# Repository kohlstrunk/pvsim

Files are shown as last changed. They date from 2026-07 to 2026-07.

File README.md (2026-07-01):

PVSIM

PV-Modul-Simulator
- getestet an Hoymiles HMS-800W-2T
- erlaubt DC-seitige Einstellung der Einspeiseleistung

Enthält:
- WinAVR-Projekt
- Eagle-Schaltplan und Layout
- Fertigungsdaten

Entwicklungsstand
- Erprobung 2-Kanalig an beiden separaten MPPT-Kanälen
- Erprobung 1-kanalig mit parallel geschalteten MPPT-Kanälen
- Erprobung mit Si-H-Brücke 50V 50A bei 62kHz Schaltfrequenz

Perspektive:
- Umstellung auf 250kHz GaN-Halbbrücke 20A mit parallel geschalteten MPPT-Kanälen

Links:
- https://www.mikrocontroller.net/topic/585740
- https://epc-co.com/epc/products/gan-fets-and-ics/epc23109

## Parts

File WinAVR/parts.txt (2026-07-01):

https://www.reichelt.de/de/de/shop/produkt/dc_dc-wandler_75_v_sip-396833
https://www.reichelt.de/de/de/shop/produkt/dc_dc-wandler_72_v_sip-396834

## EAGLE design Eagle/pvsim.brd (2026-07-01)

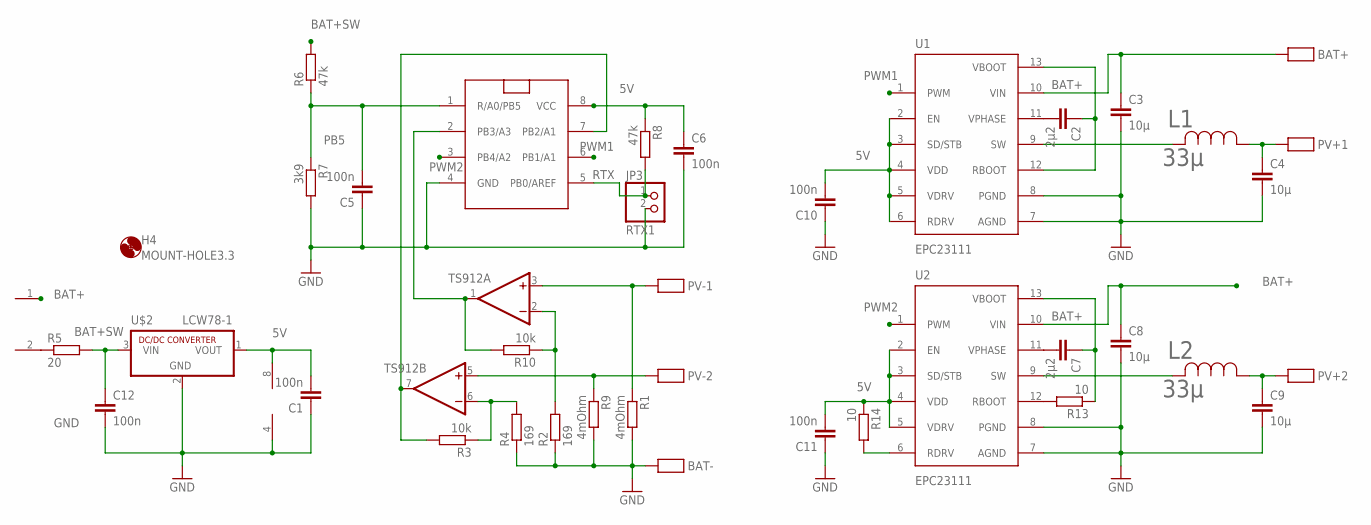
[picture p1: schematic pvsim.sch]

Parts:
BAT+: SMD_10X5
BAT-: SMD_10X5
C1, C5, C6, C10, C11, C12: 100n; C0805
C2: 2µ2; C0805K
C3, C4, C8, C9: 10µ; C1210K
C7: 2µ2; C1206K
FK1: Start; DG250-3.5-2
H4: MOUNT-HOLE3.3; 3,3
JP3: RTX1; 1X02
L1, L2: 33µ; IND_PA4349.333ANLT_PUL-M
PV+1, PV+2: SMD_10X5
PV-1, PV-2: SMD_10X5
R1, R9: 4mOhm; R2512
R2, R4: 169; R0805
R3, R10: 10k; R0805
R5: 20; 0207/10
R6, R8: 47k; R0805
R7: 3k9; R0805
R13, R14: 10; R0805
TS912: 2AMP_P8+4D; SO08
U1, U2: EPC23111; EPC23111_QFN13_EPC_LP
U$2: LCW78-1; SIP3
U$4: FUNKY; FUNKYTINY

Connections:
5V: C1.2, C6.1, C10.2, C11.2, R8.1, R14.1, TS912.8 (V+), U1.2 (EN), U1.3 (SD/STB), U1.4 (VDD), U1.5 (VDRV), U1.6 (RDRV), U2.2 (EN), U2.3 (SD/STB), U2.4 (VDD), U2.5 (VDRV), U$2.1 (VOUT), U$4.8 (VCC)
BAT+: BAT+.P$1, C3.1, C8.1, FK1.1, U1.10 (VIN), U2.10 (VIN)
BAT+SW: C12.1, R5.2, R6.2, U$2.3 (VIN)
BAT-: R9.2
GND: BAT-.P$1, C1.1, C3.2, C4.2, C5.1, C6.2, C8.2, C9.2, C10.1, C11.1, C12.2, JP3.2, R1.2, R2.1, R4.1, R7.2, TS912.4 (V-), U1.7 (AGND), U1.8 (PGND), U2.7 (AGND), U2.8 (PGND), U$2.2 (GND), U$4.4 (GND)
IPV1: PV-1.P$1, R1.1, TS912.3 (+IN)
IPV2: PV-2.P$1, R9.1, TS912.5 (+IN)
unnamed: R10.2, TS912.1 (OUT), U$4.2 (PB3/A3)
unnamed: R2.2, R10.1, TS912.2 (-IN)
unnamed: R3.2, TS912.7 (OUT), U$4.7 (PB2/A1)
unnamed: R3.1, R4.2, TS912.6 (-IN)
unnamed: FK1.2, R5.1
unnamed: C2.1, U1.12 (RBOOT), U1.13 (VBOOT)
unnamed: C2.2, U1.11 (VPHASE)
unnamed: C4.1, L1.1, PV+1.P$1
unnamed: L1.2, U1.9 (SW)
unnamed: C7.1, R13.1, U2.13 (VBOOT)
unnamed: C7.2, U2.11 (VPHASE)
unnamed: L2.2, U2.9 (SW)
unnamed: C9.1, L2.1, PV+2.P$1
unnamed: R13.2, U2.12 (RBOOT)
PB5: C5.2, R6.1, R7.1, U$4.1 (R/A0/PB5)
PWM1: U1.1 (PWM), U$4.6 (PB1/A1)
PWM2: U2.1 (PWM), U$4.3 (PB4/A2)
RTX: JP3.1, R8.2, U$4.5 (PB0/AREF)

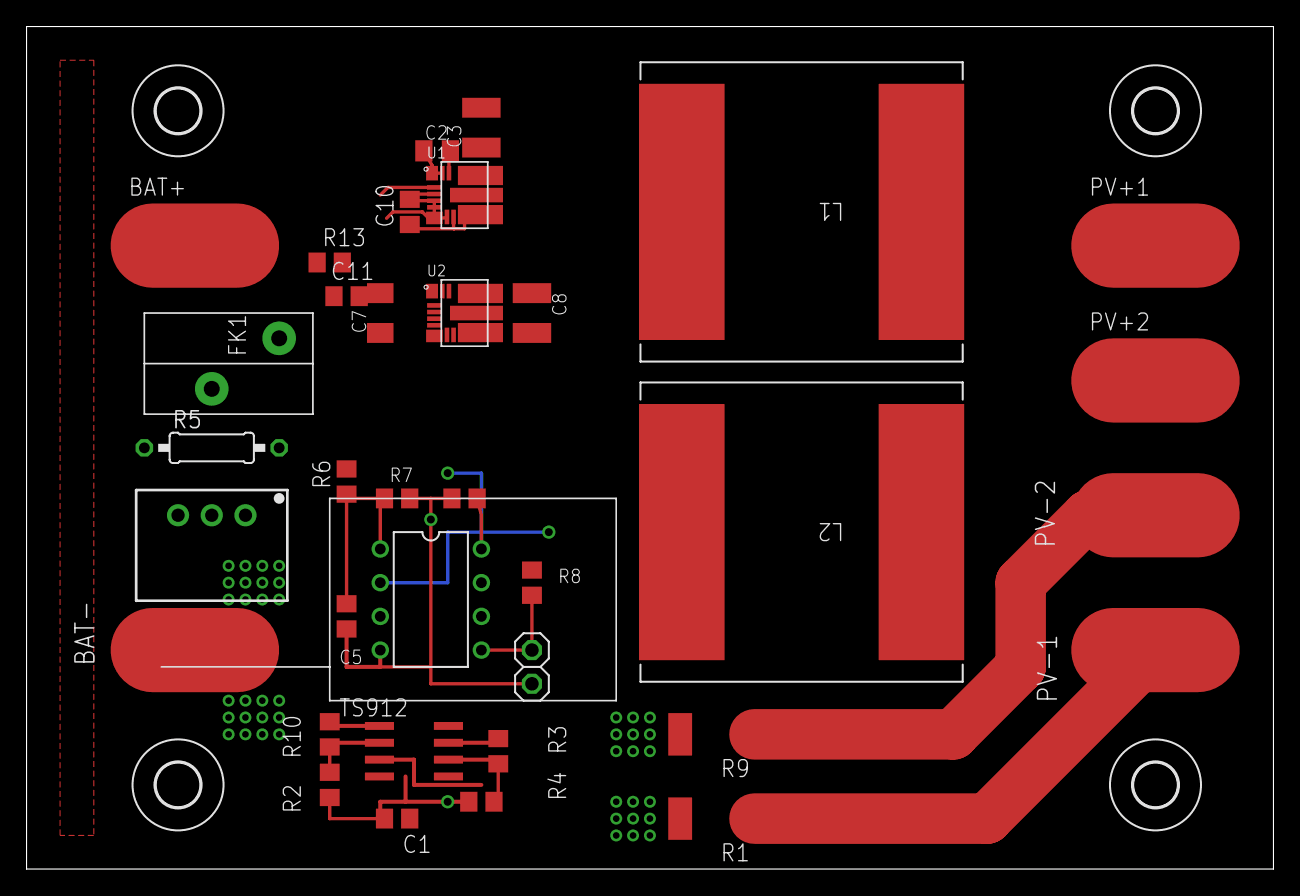
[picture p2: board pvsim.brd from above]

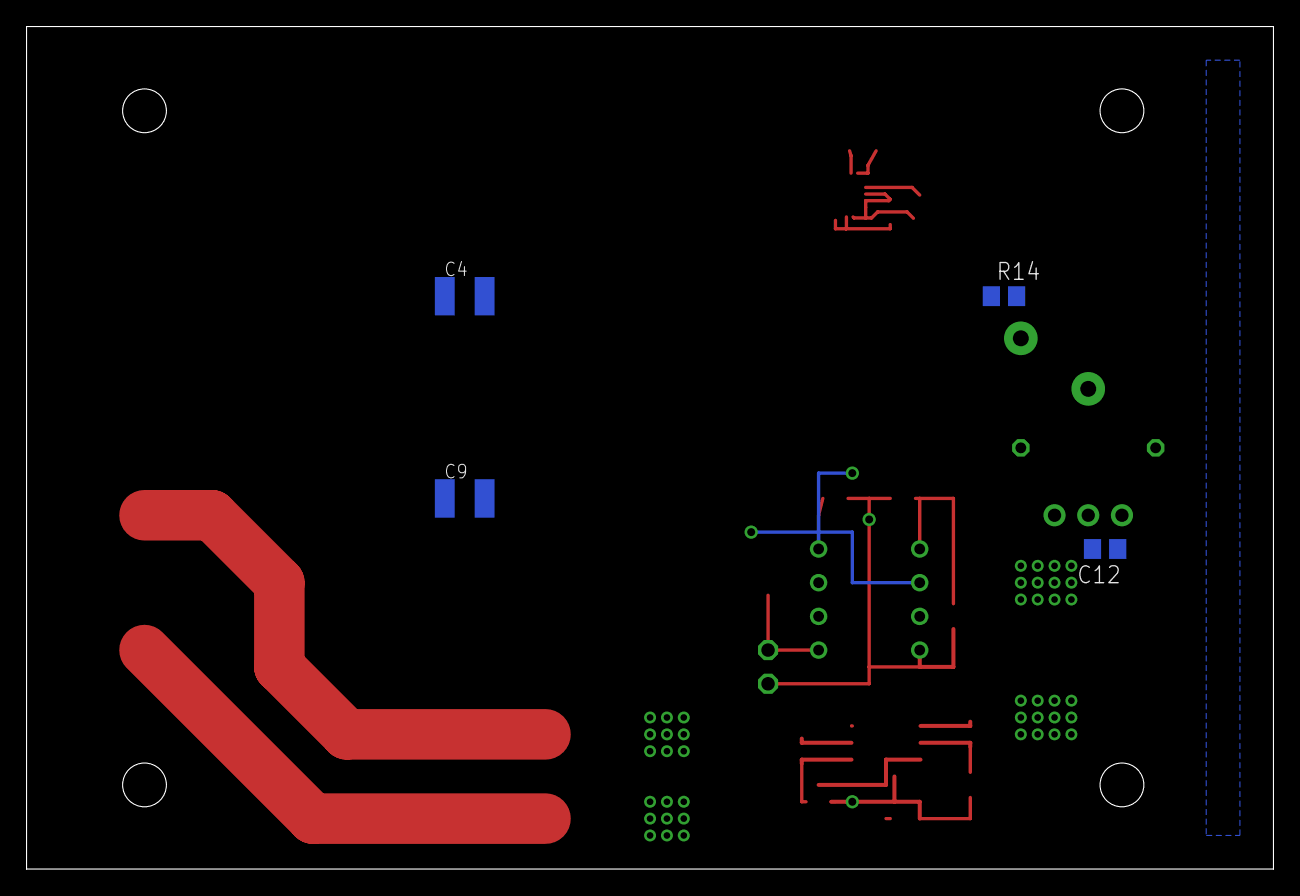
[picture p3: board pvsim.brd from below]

Board: 2 copper layers, 94.0 x 63.5 mm, 43 parts (4 on the bottom side), 24 nets.

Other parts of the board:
H1, H2, H3: MOUNT-HOLE3.3; 3,3

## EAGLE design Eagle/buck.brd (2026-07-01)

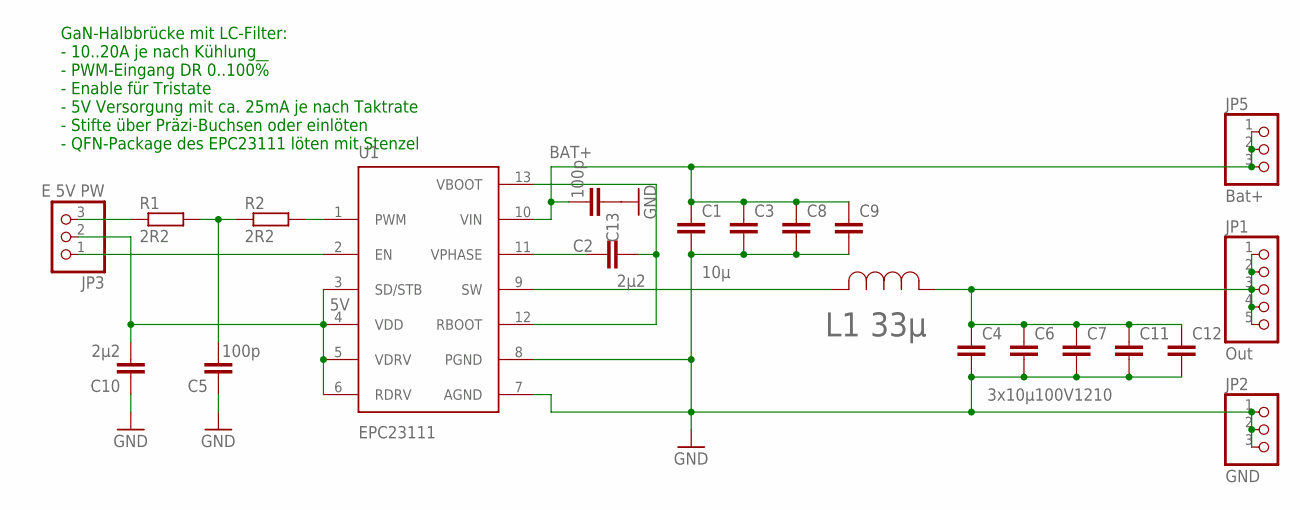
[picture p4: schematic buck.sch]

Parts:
C1, C4: 10µ; C1210K
C2, C10: 2µ2; C0603K
C3, C7, C8, C9, C11, C12: 10µ100V1210; C1210K
C5: 100p; C0603K
C6: 3x10µ100V1210; C1210K
C13: 100p; C1206K
JP1: Out; 1X05
JP2: GND; 1X03
JP3: E 5V PW; 1X03
JP5: Bat+; 1X03
L1: 33µ; IND_PA4349.333ANLT_PUL-M
R1, R2: 2R2; R0603
U1: EPC23111; EPC23111_QFN13_EPC_LP

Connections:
5V: C10.2, JP3.2, U1.3 (SD/STB), U1.4 (VDD), U1.5 (VDRV), U1.6 (RDRV)
BAT+: C1.1, C3.1, C8.1, C9.1, C13.2, JP5.1, JP5.2, JP5.3, U1.10 (VIN)
GND: C1.2, C3.2, C4.2, C5.1, C6.2, C7.2, C8.2, C9.2, C10.1, C11.2, C12.2, C13.1, JP2.1, JP2.2, JP2.3, U1.7 (AGND), U1.8 (PGND)
unnamed: C5.2, R1.2, R2.1
unnamed: R2.2, U1.1 (PWM)
unnamed: JP3.1, U1.2 (EN)
unnamed: JP3.3, R1.1
unnamed: C2.1, U1.12 (RBOOT), U1.13 (VBOOT)
unnamed: C2.2, U1.11 (VPHASE)
SW: L1.2, U1.9 (SW)
UOUT: C4.1, C6.1, C7.1, C11.1, C12.1, JP1.1, JP1.2, JP1.3, JP1.4, JP1.5, L1.1

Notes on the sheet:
GaN-Halbbrücke mit LC-Filter: - 10..20A je nach Kühlung - PWM-Eingang DR 0..100!% - Enable für Tristate - 5V Versorgung mit ca. 25mA je nach Taktrate - Stifte über Präzi-Buchsen oder einlöten - QFN-Package des EPC23111 löten mit Stenzel

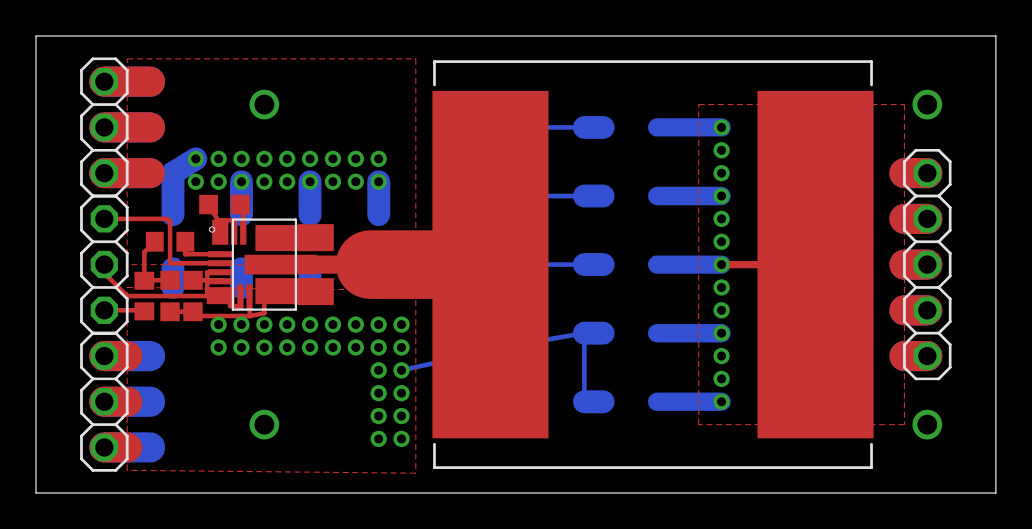
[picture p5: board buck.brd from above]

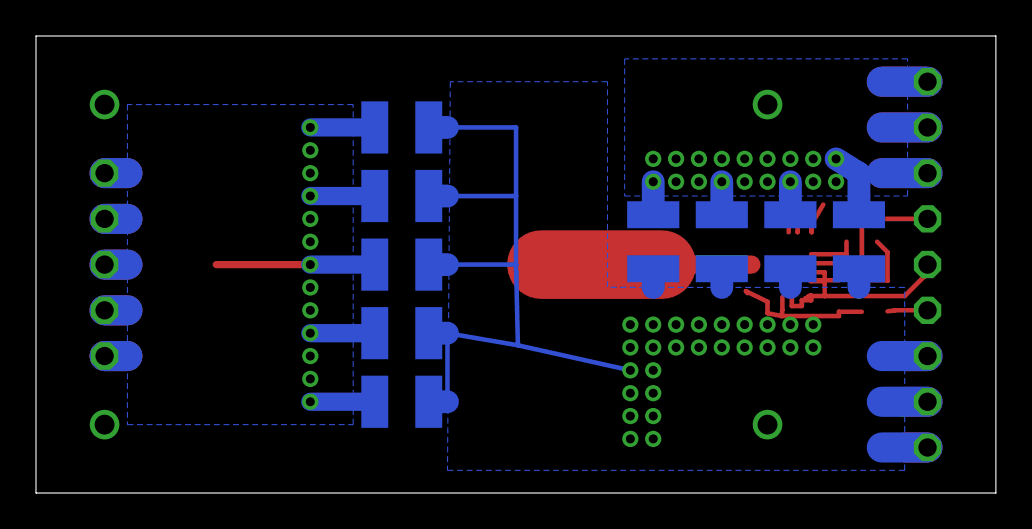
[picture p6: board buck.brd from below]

Board: 2 copper layers, 53.3 x 25.4 mm, 21 parts (9 on the bottom side), 11 nets.

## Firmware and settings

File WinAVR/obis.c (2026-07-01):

/*
https://chatgpt.com/s/t_69d2afd6cfd081919f6056d3bb99afb1

*/

#include <SoftwareSerial.h>

SoftwareSerial sml(2, 3); // RX, TX

byte bu[300];
int idx = 0;

void setup() {
  Serial.begin(115200);
  sml.begin(9600); // ggf. 19200 testen
}

void loop() {
  while (sml.available()) {
    byte b = sml.read();
    // Ringbuffer
    if (idx<sizeof(bu)){ bu[idx++]=b;} else {idx = 0;}
    // Nach OBIS 16.7.0 suchen   
	// 0x01,0x00,0x10,0x07,0x00 also 1.0.16.7.0.xxxx
    for (int i=0; i<idx-10; i++) { // weil unten i+11
//      if (bu[i]==0x01 && bu[i+1] == 0x00 && bu[i+2] == 0x10 && bu[i+3] == 0x07 && buffer[i+4] == 0x00) {
        if (bu[i]==1)&(bu[i+1]==0)&(bu[i+2]==16)&(bu[i+3]==7)&(bu[i+4]==0)) {
        long power = 0;
        power=(bu[i+8]<<24)|bu[i+9]<<16)|(bu[i+10]<<8)|(bu[i+11]);
        Serial.print("Leistung: ");Serial.print(power);Serial.println(" W");
        idx = 0; // Reset für nächsten Frame
        break;
      }
    }
  }
}

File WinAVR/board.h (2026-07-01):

#include <avr/io.h>

// Pin-Belegung und IO-Makros

#define TBIT     	104    					// ideal:104/9600baud 
#define TOUT 		250		 				// xTBIT max.8bit/25ms warten bis RX-Abbruch
#define TABT		40						// +10µs=50 Abtastposition [µs], 70 @ Pullup=30k

// Pin-Belegung
#define UBPin		5						// ADC0
#define PWMBPin		4						// OCR1B
#define I1Pin		3						// ADC3
#define I2Pin    	2						// ADC1
#define PWMAPin		1						// OCR1A
#define RTXPin		0						// RTX

// Pin-Steuerung
//#define LED_T 	PIN_TOGGLE(B,LEDPin)
//#define LED_H	 	PIN_HIGH(B,LEDPin)
//#define LED_L		PIN_LOW(B,LEDPin)
#define PWMA_L		PIN_LOW(B,PWMAPin)
#define PWMB_L		PIN_LOW(B,PWMBPin)
#define PWMA_IN		PIN_INPUT(B,PWMAPin);
#define PWMB_IN		PIN_INPUT(B,PWMBPin);
#define RTX_S		PIN_GET(B,RTXPin)		// Eingang abtasten
#define RTX_PU  	PIN_PULLUP(B,RTXPin)	// pullup: als Eingang, High
#define RTX_PD 		PIN_LOW(B,RTXPin)		// pulldown: Low, Ausgang

#define PIN_HIGH(port, pin)   do { PORT##port |= (1 << pin); DDR##port |= (1 << pin); } while(0)
#define PIN_LOW(port, pin)    do { PORT##port &= ~(1 << pin);DDR##port |= (1 << pin); } while(0)
#define PIN_PULLUP(port, pin) do { DDR##port &= ~(1 << pin); PORT##port |= (1 << pin); } while(0)
#define PIN_INPUT( port, pin) do { DDR##port &= ~(1 << pin); PORT##port &= ~(1 << pin); } while(0)
#define PIN_GET(port, pin)    ((PIN##port & (1 << pin)) != 0)
#define PIN_TOGGLE(port, pin) do { PORT##port ^= (1 << pin); DDR##port |= (1 << pin); } while(0)
//#define PIN_TOGGLE(port, pin) (PIN##port  |= (1 << pin)) atomar, aber nicht portabel 

// ADC
#define MUXAD0	0							// VCCRef PB5 ADC0
#define MUXAD1	(1<<MUX0)					// VCCRef PB2 ADC1
#define MUXAD3	((1<<MUX1)|(1<<MUX0))		// VCCRef PB3 ADC3

// Interrupt-Steuerung
#define TBIF_S		((TIFR>>OCF0B)&1)		// TB-IF abfragen
#define TBIF_D		(TIFR = (1<<OCF0B))		// schreiben einer 1 auf TB-IF löscht es, ohne zu verODERN
#define PCIF_S		((GIFR>>PCIF)&1)		// PCIF abfragen
#define RXI_E		(PCMSK |=  (1<<RTXPin))	// PORTBx=PCINTx=RTX_Pin
#define RXI_D		(PCMSK &= ~(1<<RTXPin))	// PORTBx=PCINTx=RTX_Pin
#define PCI_E		(GIMSK |=  (1<<PCIE))	// enable pin change interrupt - geht auf INT0
//#define PCI_D		(GIMSK &= ~(1<<PCIE))	// disable pin change interrupt - geht auf INT0

#define CMDMAXI		32//64					// max. Kommandolänge

enum {STA,D0,D1,D2,D3,D4,D5,D6,D7,STP,RDY}; // Serial 
enum {TNO,TYES};							// Transmission 
enum {NEIN,JA};

volatile uint8_t txi,uc,rxi,outran,intran;	// RTX: Taktphasen,Sendepuffer,Transmissionen				
volatile long rtsec,rtusec;					// Sekunden und Mikrosekunden (TBIT-Auflösung) seit Reset

volatile uint8_t cmdf; 						// cmd handshake
char cmd[CMDMAXI+1];						// Kommandopuffer (volatile nicht möglich)

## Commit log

2026-07-01 Initial project import
    [buck.brd, buck.sch, pvsim.brd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]
2026-07-01 mit buck Gerbers
    [buck.GBL, buck.GBO, buck.GBP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]
2026-07-01 mit Eagle Rev1
    [pvsim.GBL, pvsim.GBO, pvsim.GBP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]

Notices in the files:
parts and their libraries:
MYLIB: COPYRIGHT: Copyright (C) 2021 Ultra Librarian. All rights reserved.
